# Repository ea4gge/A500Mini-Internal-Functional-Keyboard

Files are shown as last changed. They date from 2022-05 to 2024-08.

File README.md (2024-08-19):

# The A500Mini AmigaWave and RetroWiki's Internal Functional Keyboard Project

<br>
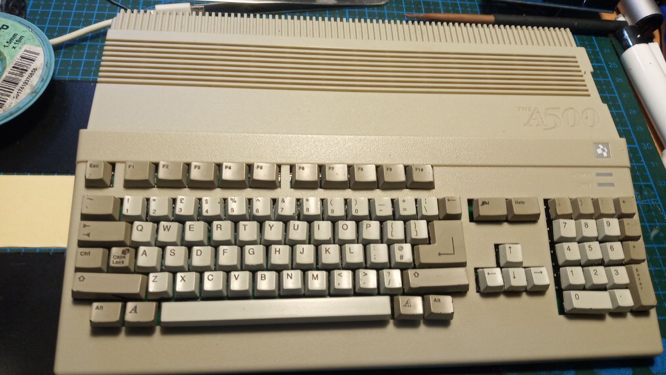
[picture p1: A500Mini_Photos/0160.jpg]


<br>

This is project of the A500Mini internal functional keyboard, based in 32U4 processor (Arduino leonardo, for example).

Actually it is working as final release, feel free to use, modify, recreate, ...

<br>
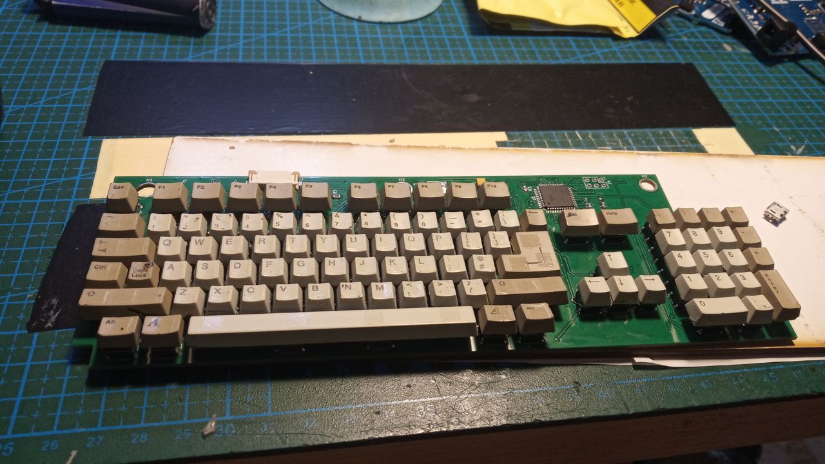
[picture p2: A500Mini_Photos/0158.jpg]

<br>

<br>
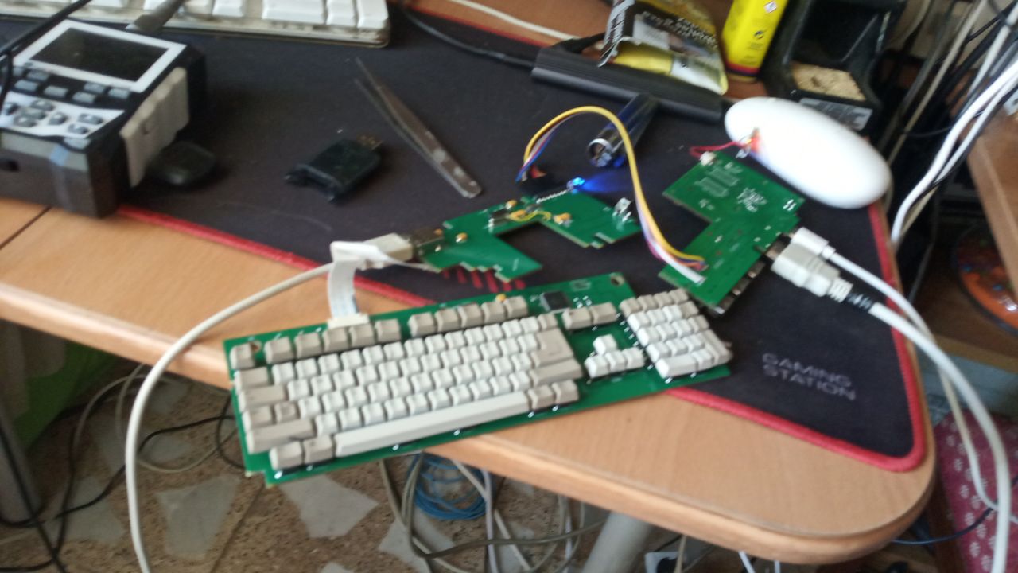
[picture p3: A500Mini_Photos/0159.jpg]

<br>

<br>
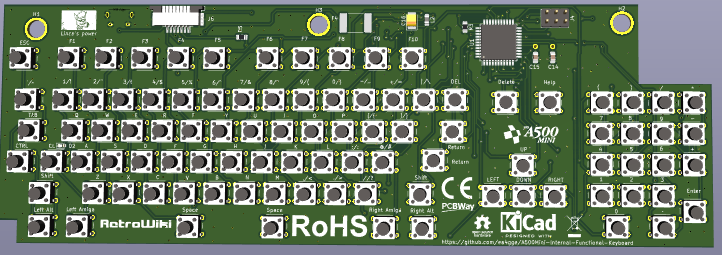
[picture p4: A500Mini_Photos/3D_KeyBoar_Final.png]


<br>

<br>
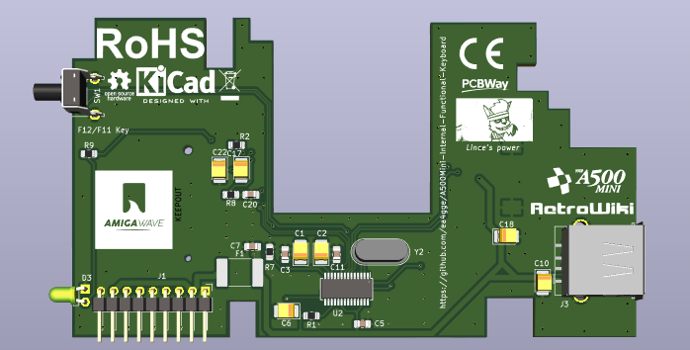
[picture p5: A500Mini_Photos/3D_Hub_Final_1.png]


<br>

# The features:

1.- HID internal fully functional keyboard, with F12 key in the "eject" button of the disk drive, CAPS Lock led, ...

2.- Internal 4 USB's HUB: One for the keyboard, one for the SD reader, one internal free (for network, for example) tha last one for the rear original placed USB on the main unit (because one of the original populated USB must be used por the hub's imput)

3.- SD card's reader exactly in the floppy disk's place.

4.- A lot of smiles after the fabrication :D 

The readme file and the help file for the fabrication is WIP at the moment.

All the mechanical procedures are made by Kikems_Retro.

The presentation of the first prototype  (one weekend JOB) was in the youtube's AmigaWave program. We have also presented in the "Posadas party", in Spain 

The inspiration for my own code was from the "Armapad36v2" because is my firstt program of an USB Keyboard. Many thanks for the Author of this!!!

Spetial thanks to EA4EOZ. He has had the idea of use the Eject button and gave me a lot of help in the code of the Arduino

<br>
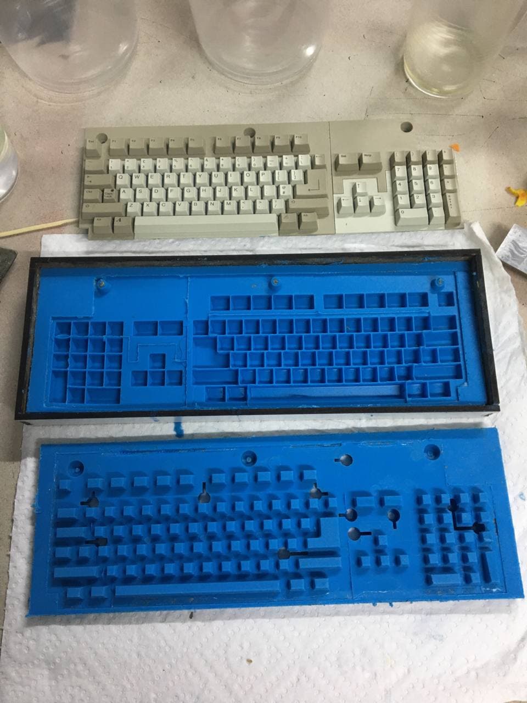
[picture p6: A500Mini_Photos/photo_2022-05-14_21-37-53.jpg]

<br>

<br>
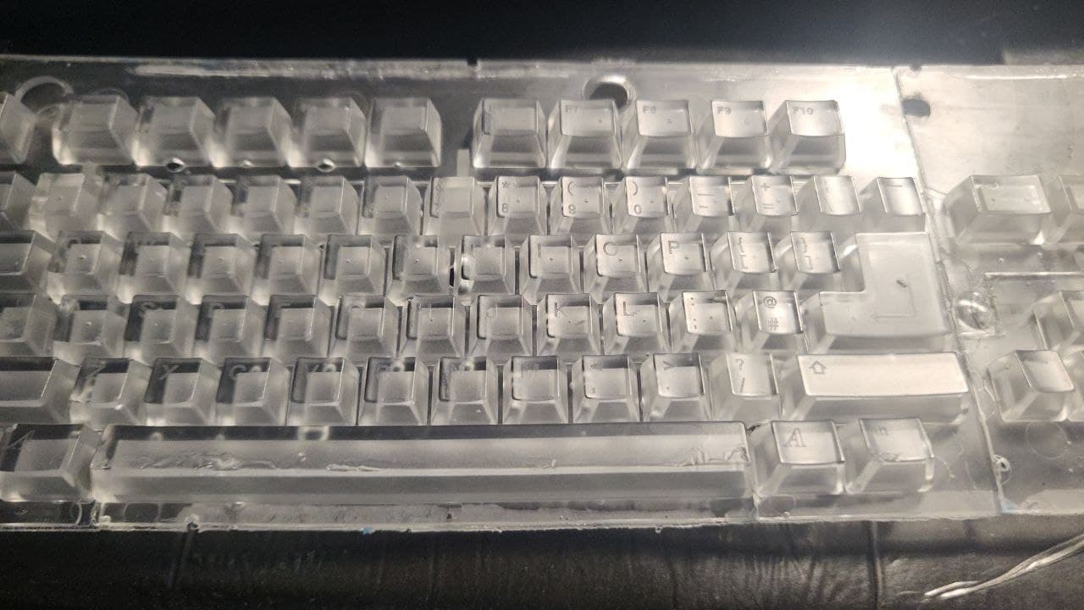
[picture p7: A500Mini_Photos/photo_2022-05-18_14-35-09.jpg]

<br>

Many thanks to all and Enjoy!!

Lince// EA4GGE

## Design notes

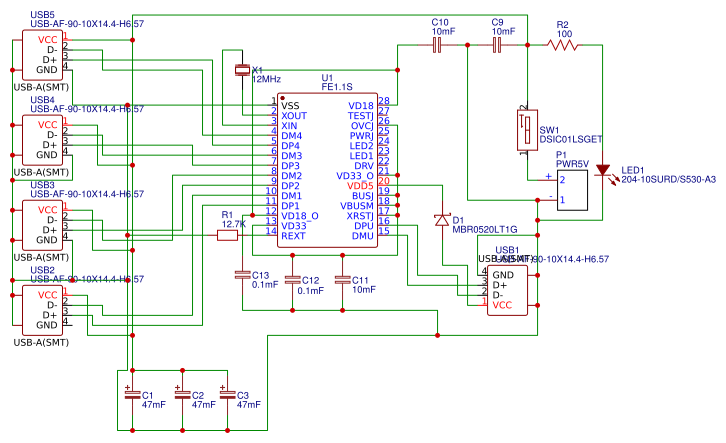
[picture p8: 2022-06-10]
FE11S_Schematic.png

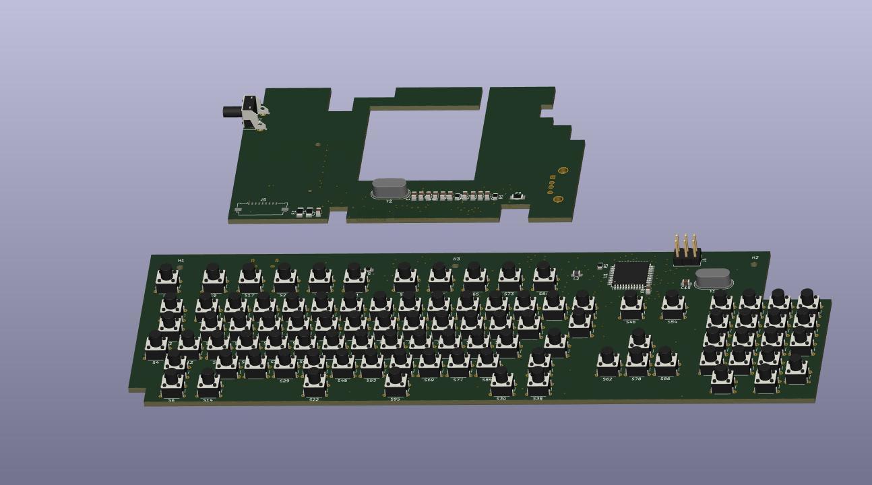
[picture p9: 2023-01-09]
3D_Model.jpg

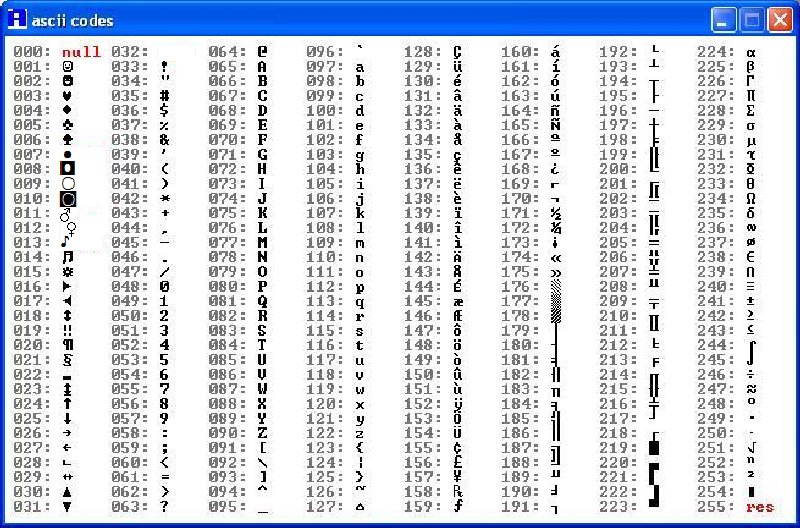
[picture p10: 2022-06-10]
ascii_code.jpg

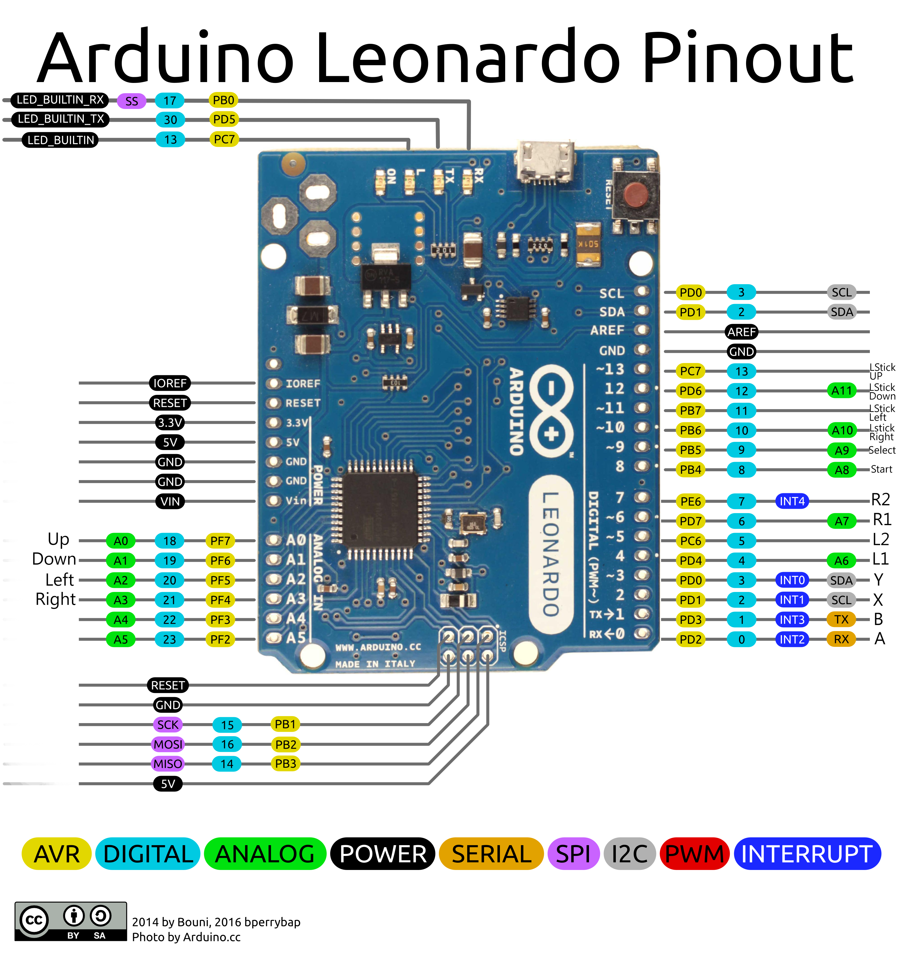
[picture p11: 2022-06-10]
41727827-dbd470d2-75a7-11e8-8bf4-4bd52fe4657b.png

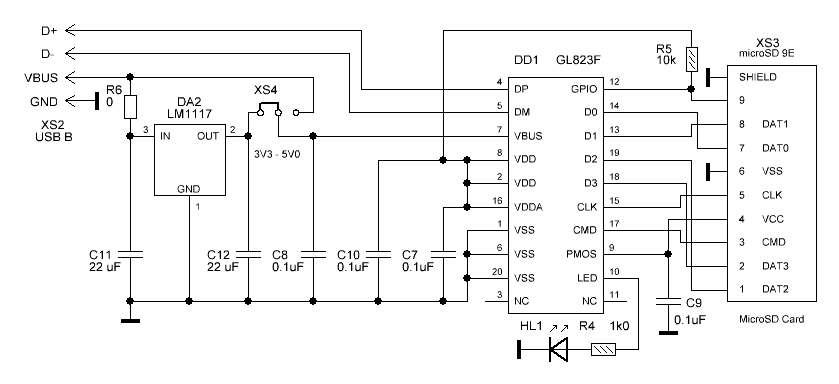
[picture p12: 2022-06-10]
anatomy-and-cloning-of-the-usb-adapter-for-sd-card-geektimes.gif

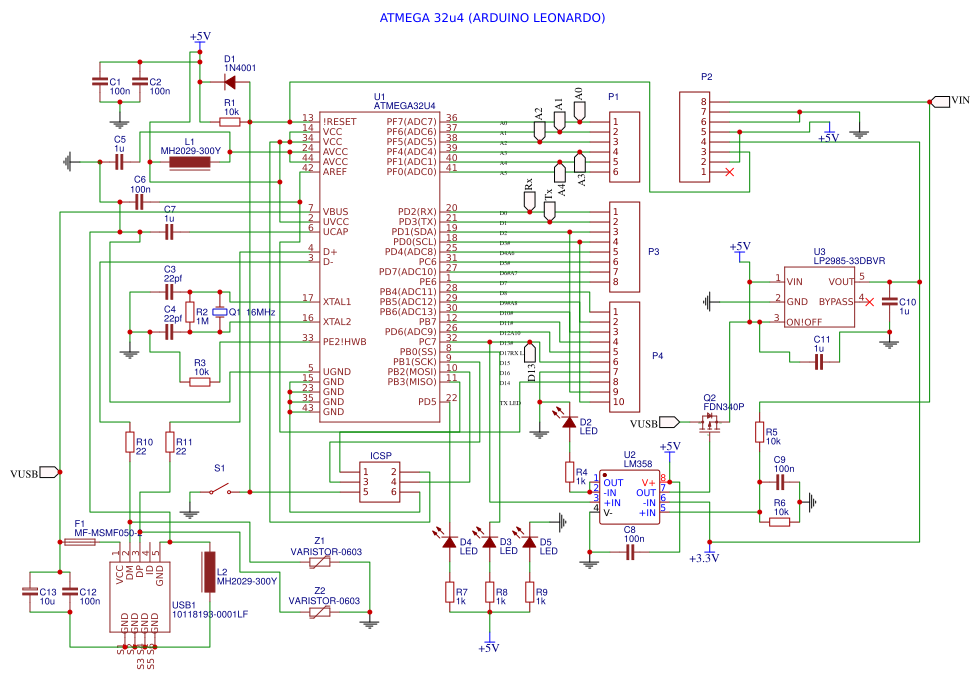
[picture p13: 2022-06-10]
Leonardo_compatible.png

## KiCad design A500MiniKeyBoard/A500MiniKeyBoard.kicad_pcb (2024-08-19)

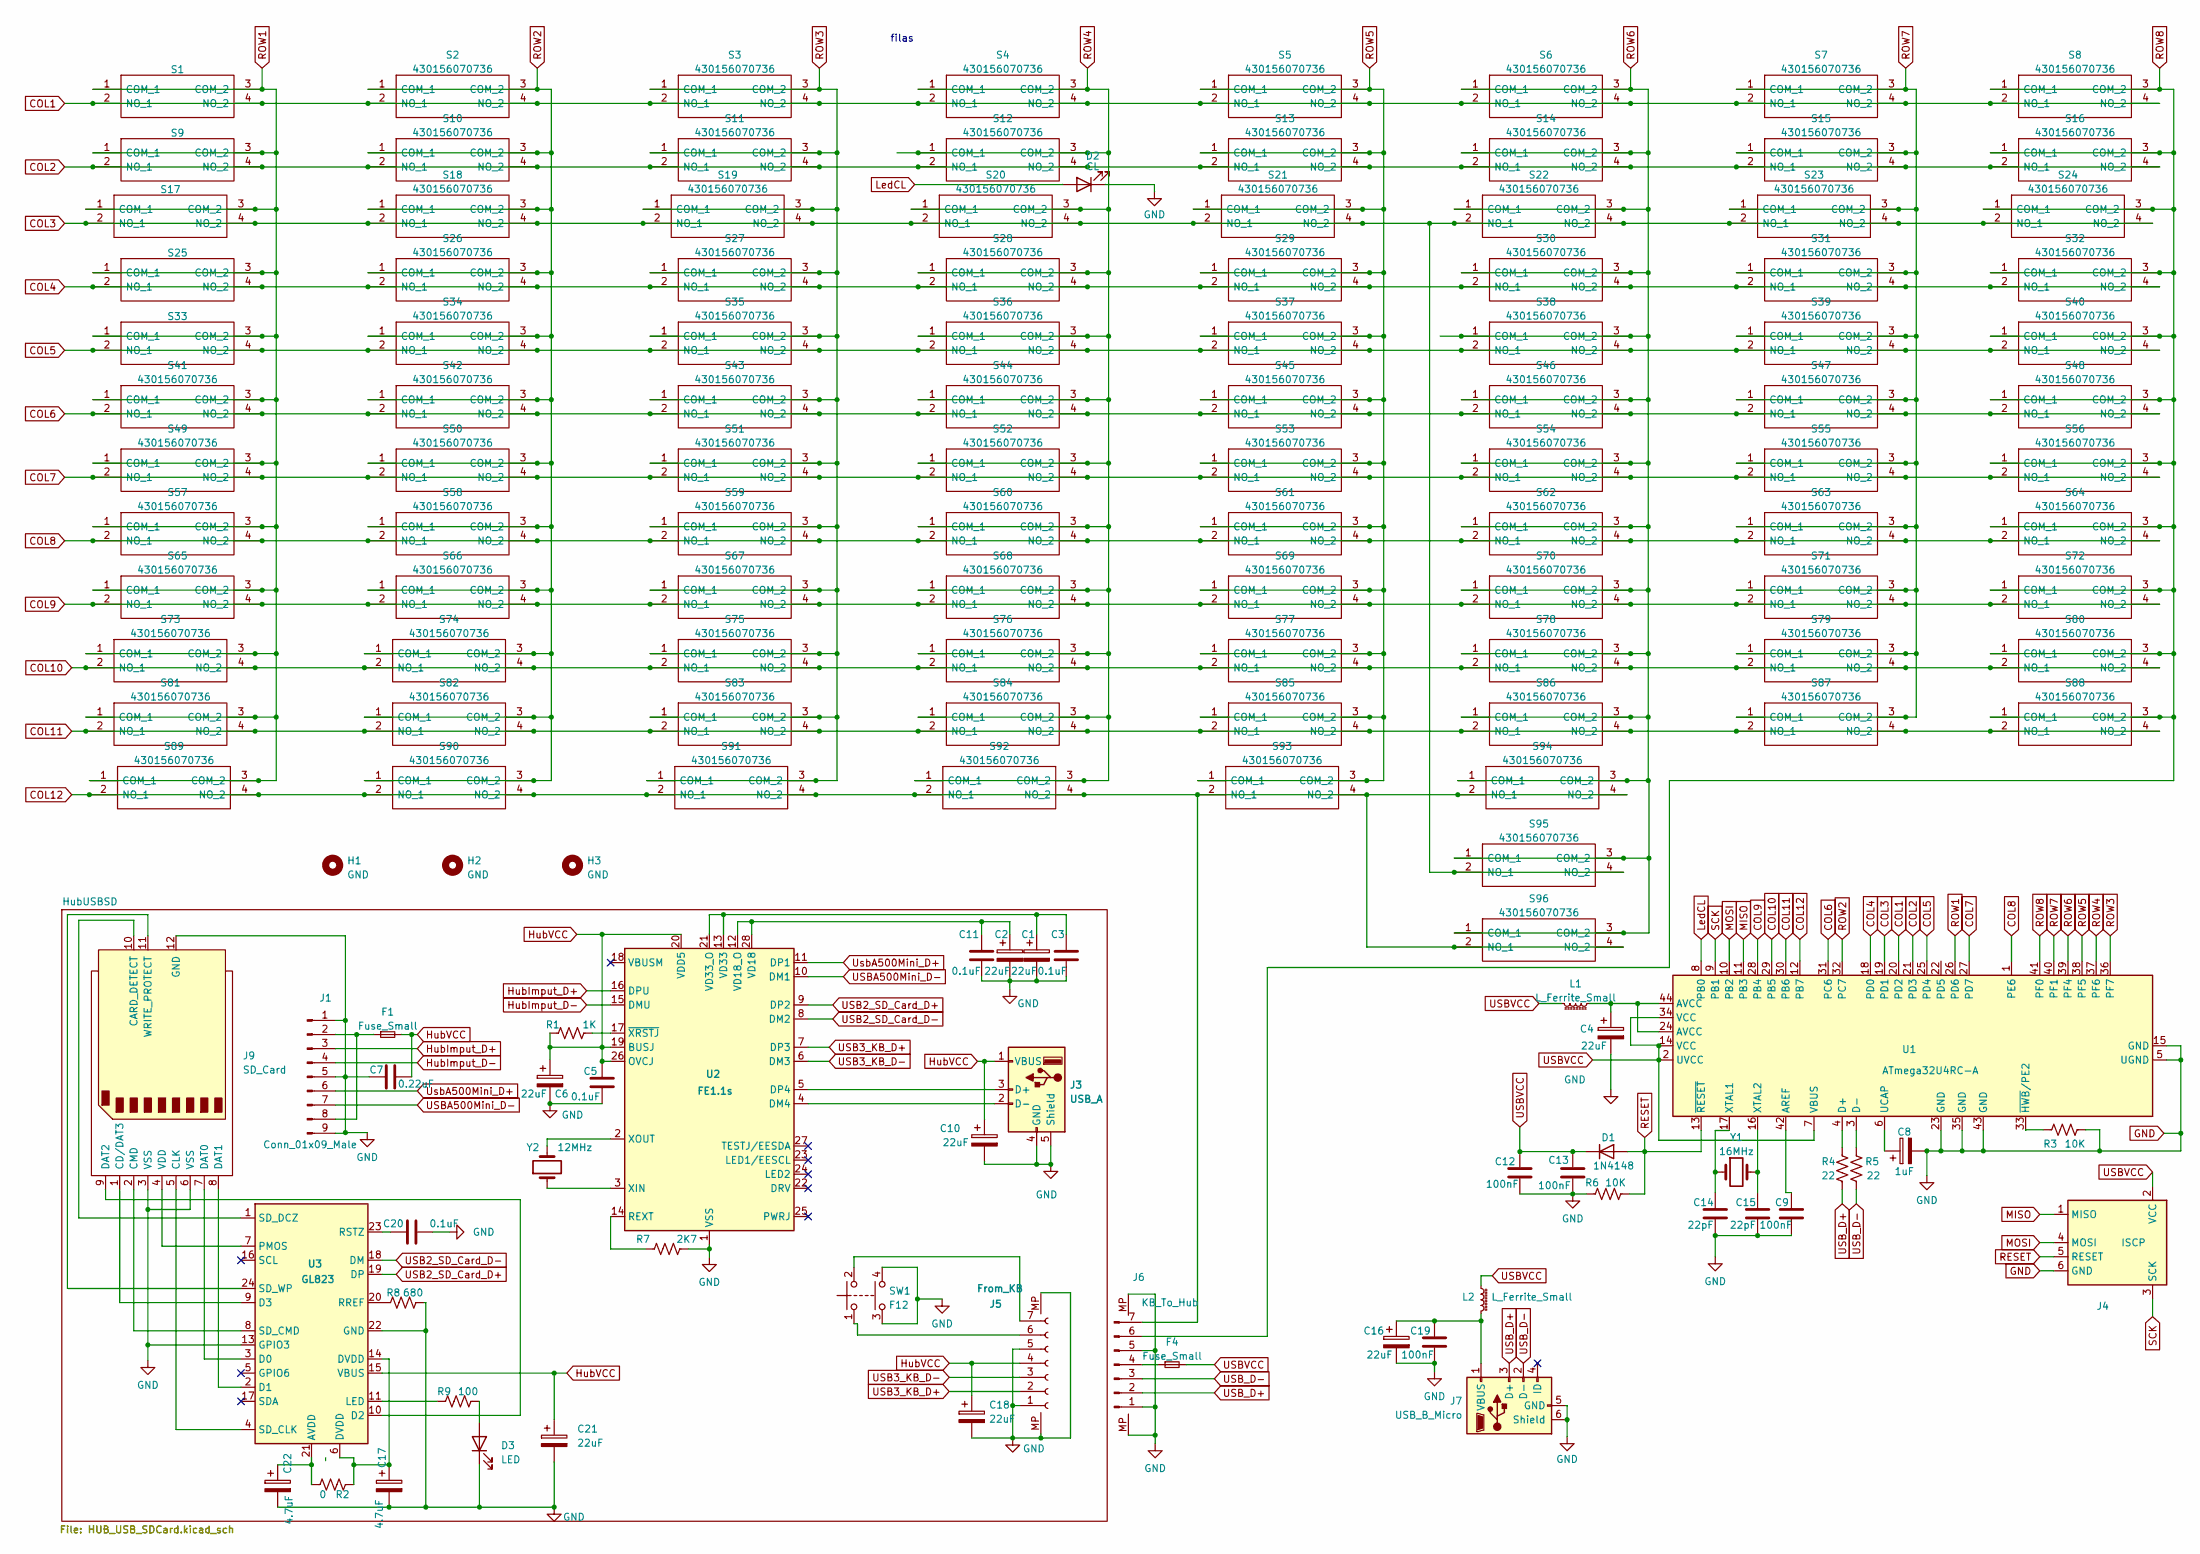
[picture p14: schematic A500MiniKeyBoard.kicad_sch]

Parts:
C1, C2, C4, C6, C10, C16, C18, C21: 22uF; CP_EIA-3528-21_Kemet-B_Pad1.50x2.35mm_HandSolder
C3, C5, C11, C20: 0.1uF; C_0805_2012Metric_Pad1.18x1.45mm_HandSolder
C7: 0.22uF; C_0805_2012Metric_Pad1.18x1.45mm_HandSolder
C8: 1uF; CP_EIA-3528-21_Kemet-B_Pad1.50x2.35mm_HandSolder
C9, C12, C13, C19: 100nF; C_0805_2012Metric_Pad1.18x1.45mm_HandSolder
C14, C15: 22pF; C_0805_2012Metric_Pad1.18x1.45mm_HandSolder
C17, C22: 4.7uF; CP_EIA-3528-21_Kemet-B_Pad1.50x2.35mm_HandSolder
D1: 1N4148; D_0805_2012Metric_Pad1.15x1.40mm_HandSolder
D2: CL; LED_0603_1608Metric
D3: LED; LED_D3.0mm_Horizontal_O1.27mm_Z2.0mm
F1, F4: Fuse_Small; Fuse_2920_7451Metric_Pad2.10x5.45mm_HandSolder
H1, H2, H3: GND; MountingHole_2.1mm
J1: Conn_01x09_Male; PinHeader_1x09_P2.54mm_Horizontal
J3: USB_A; USB_A_Molex_67643_Horizontal
J4: ISCP; PinHeader_2x03_P2.54mm_Vertical
J5: From_KB; TE_84953-7_1x07-1MP_P1.0mm_Horizontal
J6: KB_To_Hub; TE_84953-7_1x07-1MP_P1.0mm_Horizontal
J7: USB_B_Micro; USB_Micro-B_Amphenol_10118194_Horizontal
J9: SD_Card; SD_TE_2041021
L1, L2: L_Ferrite_Small; L_0805_2012Metric_Pad1.05x1.20mm_HandSolder
R1: 1K; R_0805_2012Metric_Pad1.20x1.40mm_HandSolder
R2: 0; R_0805_2012Metric_Pad1.20x1.40mm_HandSolder
R3, R6: 10K; R_0805_2012Metric_Pad1.20x1.40mm_HandSolder
R4, R5: 22; R_0805_2012Metric_Pad1.20x1.40mm_HandSolder
R7: 2K7; R_0805_2012Metric_Pad1.20x1.40mm_HandSolder
R8: 680; R_0805_2012Metric_Pad1.20x1.40mm_HandSolder
R9: 100; R_0805_2012Metric_Pad1.20x1.40mm_HandSolder
S1, S2, S3, S4, S5, S6, S7, S8, S9, S10, S11, S12, S13, S14, S15, S16, S17, S18, S19, S20, S21, S22, S23, S24, S25, S26, S27, S28, S29, S30, S31, S32, S33, S34, S35, S36, S37, S38, S39, S40, S41, S42, S43, S44, S45, S46, S47, S48, S49, S50, S51, S52, S53, S54, S55, S56, S57, S58, S59, S60, S61, S62, S63, S64, S65, S66, S67, S68, S69, S70, S71, S72, S73, S74, S75, S76, S77, S78, S79, S80, S81, S82, S83, S84, S85, S86, S87, S88, S89, S90, S91, S92, S93, S94, S95, S96: 430156070736; SW_PUSH_6mm_H7.3mm_mia; Mouser Part Number N/A
SW1: F12; SW_Tactile_SPST_Angled_PTS645Vx83-2LFS
U1: ATmega32U4RC-A; TQFP-44_10x10mm_P0.8mm
U2: FE1.1s; SSOP-28_3.9x9.9mm_P0.635mm
U3: GL823; SSOP-24_3.9x8.7mm_P0.635mm
Y1: 16MHz; Crystal_HC49-4H_Vertical
Y2: 12MHz; Crystal_HC49-4H_Vertical

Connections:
COL1: S1.2 (NO_1), S1.4 (NO_2), S2.2 (NO_1), S2.4 (NO_2), S3.2 (NO_1), S3.4 (NO_2), S4.2 (NO_1), S4.4 (NO_2), S5.2 (NO_1), S5.4 (NO_2), S6.2 (NO_1), S6.4 (NO_2), S7.2 (NO_1), S7.4 (NO_2), S8.2 (NO_1), S8.4 (NO_2), U1.20 (PD2)
COL2: S9.2 (NO_1), S9.4 (NO_2), S10.2 (NO_1), S10.4 (NO_2), S11.2 (NO_1), S11.4 (NO_2), S12.2 (NO_1), S12.4 (NO_2), S13.2 (NO_1), S13.4 (NO_2), S14.2 (NO_1), S14.4 (NO_2), S15.2 (NO_1), S15.4 (NO_2), S16.2 (NO_1), S16.4 (NO_2), U1.21 (PD3)
COL3: S17.2 (NO_1), S17.4 (NO_2), S18.2 (NO_1), S18.4 (NO_2), S19.2 (NO_1), S19.4 (NO_2), S20.2 (NO_1), S20.4 (NO_2), S21.2 (NO_1), S21.4 (NO_2), S22.2 (NO_1), S22.4 (NO_2), S23.2 (NO_1), S23.4 (NO_2), S24.2 (NO_1), S24.4 (NO_2), S95.2 (NO_1), S95.4 (NO_2), U1.19 (PD1)
COL4: S25.2 (NO_1), S25.4 (NO_2), S26.2 (NO_1), S26.4 (NO_2), S27.2 (NO_1), S27.4 (NO_2), S28.2 (NO_1), S28.4 (NO_2), S29.2 (NO_1), S29.4 (NO_2), S30.2 (NO_1), S30.4 (NO_2), S31.2 (NO_1), S31.4 (NO_2), S32.2 (NO_1), S32.4 (NO_2), U1.18 (PD0)
COL5: S33.2 (NO_1), S33.4 (NO_2), S34.2 (NO_1), S34.4 (NO_2), S35.2 (NO_1), S35.4 (NO_2), S36.2 (NO_1), S36.4 (NO_2), S37.2 (NO_1), S37.4 (NO_2), S38.2 (NO_1), S38.4 (NO_2), S39.2 (NO_1), S39.4 (NO_2), S40.2 (NO_1), S40.4 (NO_2), U1.25 (PD4)
COL6: S41.2 (NO_1), S41.4 (NO_2), S42.2 (NO_1), S42.4 (NO_2), S43.2 (NO_1), S43.4 (NO_2), S44.2 (NO_1), S44.4 (NO_2), S45.2 (NO_1), S45.4 (NO_2), S46.2 (NO_1), S46.4 (NO_2), S47.2 (NO_1), S47.4 (NO_2), S48.2 (NO_1), S48.4 (NO_2), U1.31 (PC6)
COL7: S49.2 (NO_1), S49.4 (NO_2), S50.2 (NO_1), S50.4 (NO_2), S51.2 (NO_1), S51.4 (NO_2), S52.2 (NO_1), S52.4 (NO_2), S53.2 (NO_1), S53.4 (NO_2), S54.2 (NO_1), S54.4 (NO_2), S55.2 (NO_1), S55.4 (NO_2), S56.2 (NO_1), S56.4 (NO_2), U1.27 (PD7)
COL8: S57.2 (NO_1), S57.4 (NO_2), S58.2 (NO_1), S58.4 (NO_2), S59.2 (NO_1), S59.4 (NO_2), S60.2 (NO_1), S60.4 (NO_2), S61.2 (NO_1), S61.4 (NO_2), S62.2 (NO_1), S62.4 (NO_2), S63.2 (NO_1), S63.4 (NO_2), S64.2 (NO_1), S64.4 (NO_2), U1.1 (PE6)
COL9: S65.2 (NO_1), S65.4 (NO_2), S66.2 (NO_1), S66.4 (NO_2), S67.2 (NO_1), S67.4 (NO_2), S68.2 (NO_1), S68.4 (NO_2), S69.2 (NO_1), S69.4 (NO_2), S70.2 (NO_1), S70.4 (NO_2), S71.2 (NO_1), S71.4 (NO_2), S72.2 (NO_1), S72.4 (NO_2), U1.28 (PB4)
COL10: S73.2 (NO_1), S73.4 (NO_2), S74.2 (NO_1), S74.4 (NO_2), S75.2 (NO_1), S75.4 (NO_2), S76.2 (NO_1), S76.4 (NO_2), S77.2 (NO_1), S77.4 (NO_2), S78.2 (NO_1), S78.4 (NO_2), S79.2 (NO_1), S79.4 (NO_2), S80.2 (NO_1), S80.4 (NO_2), U1.29 (PB5)
COL11: S81.2 (NO_1), S81.4 (NO_2), S82.2 (NO_1), S82.4 (NO_2), S83.2 (NO_1), S83.4 (NO_2), S84.2 (NO_1), S84.4 (NO_2), S85.2 (NO_1), S85.4 (NO_2), S86.2 (NO_1), S86.4 (NO_2), S87.2 (NO_1), S87.4 (NO_2), S88.2 (NO_1), S88.4 (NO_2), U1.30 (PB6)
COL12: J6.7, S89.2 (NO_1), S89.4 (NO_2), S90.2 (NO_1), S90.4 (NO_2), S91.2 (NO_1), S91.4 (NO_2), S92.2 (NO_1), S92.4 (NO_2), S93.2 (NO_1), S93.4 (NO_2), S94.2 (NO_1), S94.4 (NO_2), S96.2 (NO_1), S96.4 (NO_2), U1.12 (PB7)
GND: C1.2, C2.2, C3.1, C4.2, C5.1, C6.2, C7.1, C8.2, C9.2, C10.2, C11.2, C12.1, C13.1, C14.2, C15.2, C16.2, C17.2, C18.2, C19.1, C20.1, C21.2, C22.2, D2.1 (K), D3.1 (K), J1.1, J1.5, J1.9, J3.4 (GND), J3.5 (Shield), J4.6 (GND), J5.1, J5.5, J5.MP, J6.1, J6.5, J6.MP, J7.5 (GND), J7.6 (Shield), J9.3 (VSS), J9.6 (VSS), J9.12 (GND), R3.2, R6.1, R7.1, R8.1, SW1.3, SW1.4, U1.5 (UGND), U1.15 (GND), U1.23 (GND), U1.35 (GND), U1.43 (GND), U2.1 (VSS), U3.13 (GPIO3), U3.22 (GND)
HubImput_D+: J1.3, U2.16 (DPU)
HubImput_D-: J1.4, U2.15 (DMU)
HubVCC: C5.2, C6.1, C7.2, C10.1, C18.1, C21.1, F1.2, J3.1 (VBUS), J5.4, R1.2, U2.19 (BUSJ), U2.20 (VDD5), U2.26 (OVCJ), U3.15 (VBUS)
LedCL: D2.2 (A), U1.8 (PB0)
MISO: J4.1 (MISO), U1.11 (PB3)
MOSI: J4.4 (MOSI), U1.10 (PB2)
unnamed: C4.1, L1.1, U1.24 (AVCC), U1.44 (AVCC)
unnamed: C17.1, R2.2, U3.6 (DVDD), U3.14 (DVDD)
unnamed: D3.2 (A), R9.1
unnamed: F1.1, J1.2, J1.8
unnamed: J3.3 (D+), U2.5 (DP4)
unnamed: J3.2 (D-), U2.4 (DM4)
unnamed: J5.6, SW1.1
unnamed: J5.7, SW1.2
unnamed: F4.1, J6.4
unnamed: C16.1, C19.2, J7.1 (VBUS), L2.2
unnamed: J9.10 (CARD_DETECT), U3.1 (SD_DCZ)
unnamed: J9.1 (CD/DAT3), U3.9 (D3)
unnamed: J9.5 (CLK), U3.4 (SD_CLK)
unnamed: J9.2 (CMD), U3.8 (SD_CMD)
unnamed: J9.7 (DAT0), U3.3 (D0)
unnamed: J9.8 (DAT1), U3.2 (D1)
unnamed: J9.9 (DAT2), U3.10 (D2)
unnamed: J9.4 (VDD), U3.7 (PMOS)
unnamed: J9.11 (WRITE_PROTECT), U3.24 (SD_WP)
unnamed: C9.1, U1.42 (AREF)
unnamed: R4.1, U1.4 (D+)
unnamed: R5.1, U1.3 (D-)
unnamed: C8.1, U1.6 (UCAP)
unnamed: C14.1, U1.17 (XTAL1), Y1.1
unnamed: C15.1, U1.16 (XTAL2), Y1.2
unnamed: R3.1, U1.33 (~HWB/PE2)
unnamed: R7.2, U2.14 (REXT)
unnamed: C2.1, C11.1, U2.12 (VD18_O), U2.28 (VD18)
unnamed: C1.1, C3.2, U2.13 (VD33), U2.21 (VD33_O)
unnamed: U2.3 (XIN), Y2.1
unnamed: U2.2 (XOUT), Y2.2
unnamed: R1.1, U2.17 (~XRSTJ)
unnamed: C22.1, R2.1, U3.21 (AVDD)
unnamed: R9.2, U3.11 (LED)
unnamed: R8.2, U3.20 (RREF)
unnamed: C20.2, U3.23 (RSTZ)
RESET: D1.2 (A), J4.5 (RESET), R6.2, U1.13 (~RESET)
ROW1: S1.1 (COM_1), S1.3 (COM_2), S9.1 (COM_1), S9.3 (COM_2), S17.1 (COM_1), S17.3 (COM_2), S25.1 (COM_1), S25.3 (COM_2), S33.1 (COM_1), S33.3 (COM_2), S41.1 (COM_1), S41.3 (COM_2), S49.1 (COM_1), S49.3 (COM_2), S57.1 (COM_1), S57.3 (COM_2), S65.1 (COM_1), S65.3 (COM_2), S73.1 (COM_1), S73.3 (COM_2), S81.1 (COM_1), S81.3 (COM_2), S89.1 (COM_1), S89.3 (COM_2), U1.26 (PD6)
ROW2: S2.1 (COM_1), S2.3 (COM_2), S10.1 (COM_1), S10.3 (COM_2), S18.1 (COM_1), S18.3 (COM_2), S26.1 (COM_1), S26.3 (COM_2), S34.1 (COM_1), S34.3 (COM_2), S42.1 (COM_1), S42.3 (COM_2), S50.1 (COM_1), S50.3 (COM_2), S58.1 (COM_1), S58.3 (COM_2), S66.1 (COM_1), S66.3 (COM_2), S74.1 (COM_1), S74.3 (COM_2), S82.1 (COM_1), S82.3 (COM_2), S90.1 (COM_1), S90.3 (COM_2), U1.32 (PC7)
ROW3: S3.1 (COM_1), S3.3 (COM_2), S11.1 (COM_1), S11.3 (COM_2), S19.1 (COM_1), S19.3 (COM_2), S27.1 (COM_1), S27.3 (COM_2), S35.1 (COM_1), S35.3 (COM_2), S43.1 (COM_1), S43.3 (COM_2), S51.1 (COM_1), S51.3 (COM_2), S59.1 (COM_1), S59.3 (COM_2), S67.1 (COM_1), S67.3 (COM_2), S75.1 (COM_1), S75.3 (COM_2), S83.1 (COM_1), S83.3 (COM_2), S91.1 (COM_1), S91.3 (COM_2), U1.36 (PF7)
ROW4: S4.1 (COM_1), S4.3 (COM_2), S12.1 (COM_1), S12.3 (COM_2), S20.1 (COM_1), S20.3 (COM_2), S28.1 (COM_1), S28.3 (COM_2), S36.1 (COM_1), S36.3 (COM_2), S44.1 (COM_1), S44.3 (COM_2), S52.1 (COM_1), S52.3 (COM_2), S60.1 (COM_1), S60.3 (COM_2), S68.1 (COM_1), S68.3 (COM_2), S76.1 (COM_1), S76.3 (COM_2), S84.1 (COM_1), S84.3 (COM_2), S92.1 (COM_1), S92.3 (COM_2), U1.37 (PF6)
ROW5: S5.1 (COM_1), S5.3 (COM_2), S13.1 (COM_1), S13.3 (COM_2), S21.1 (COM_1), S21.3 (COM_2), S29.1 (COM_1), S29.3 (COM_2), S37.1 (COM_1), S37.3 (COM_2), S45.1 (COM_1), S45.3 (COM_2), S53.1 (COM_1), S53.3 (COM_2), S61.1 (COM_1), S61.3 (COM_2), S69.1 (COM_1), S69.3 (COM_2), S77.1 (COM_1), S77.3 (COM_2), S85.1 (COM_1), S85.3 (COM_2), S93.1 (COM_1), S93.3 (COM_2), U1.38 (PF5)
ROW6: S6.1 (COM_1), S6.3 (COM_2), S14.1 (COM_1), S14.3 (COM_2), S22.1 (COM_1), S22.3 (COM_2), S30.1 (COM_1), S30.3 (COM_2), S38.1 (COM_1), S38.3 (COM_2), S46.1 (COM_1), S46.3 (COM_2), S54.1 (COM_1), S54.3 (COM_2), S62.1 (COM_1), S62.3 (COM_2), S70.1 (COM_1), S70.3 (COM_2), S78.1 (COM_1), S78.3 (COM_2), S86.1 (COM_1), S86.3 (COM_2), S94.1 (COM_1), S94.3 (COM_2), S95.1 (COM_1), S95.3 (COM_2), S96.1 (COM_1), S96.3 (COM_2), U1.39 (PF4)
ROW7: S7.1 (COM_1), S7.3 (COM_2), S15.1 (COM_1), S15.3 (COM_2), S23.1 (COM_1), S23.3 (COM_2), S31.1 (COM_1), S31.3 (COM_2), S39.1 (COM_1), S39.3 (COM_2), S47.1 (COM_1), S47.3 (COM_2), S55.1 (COM_1), S55.3 (COM_2), S63.1 (COM_1), S63.3 (COM_2), S71.1 (COM_1), S71.3 (COM_2), S79.1 (COM_1), S79.3 (COM_2), S87.1 (COM_1), S87.3 (COM_2), U1.40 (PF1)
ROW8: J6.6, S8.1 (COM_1), S8.3 (COM_2), S16.1 (COM_1), S16.3 (COM_2), S24.1 (COM_1), S24.3 (COM_2), S32.1 (COM_1), S32.3 (COM_2), S40.1 (COM_1), S40.3 (COM_2), S48.1 (COM_1), S48.3 (COM_2), S56.1 (COM_1), S56.3 (COM_2), S64.1 (COM_1), S64.3 (COM_2), S72.1 (COM_1), S72.3 (COM_2), S80.1 (COM_1), S80.3 (COM_2), S88.1 (COM_1), S88.3 (COM_2), U1.41 (PF0)
SCK: J4.3 (SCK), U1.9 (PB1)
USB2_SD_Card_D+: U2.9 (DP2), U3.19 (DP)
USB2_SD_Card_D-: U2.8 (DM2), U3.18 (DM)
USB3_KB_D+: J5.2, U2.7 (DP3)
USB3_KB_D-: J5.3, U2.6 (DM3)
USBA500Mini_D-: J1.7, U2.10 (DM1)
USBVCC: C12.2, C13.2, D1.1 (K), F4.2, J4.2 (VCC), L1.2, L2.1, U1.2 (UVCC), U1.7 (VBUS), U1.14 (VCC), U1.34 (VCC)
USB_D+: J6.2, J7.3 (D+), R4.2
USB_D-: J6.3, J7.2 (D-), R5.2
UsbA500Mini_D+: J1.6, U2.11 (DP1)

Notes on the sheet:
filas

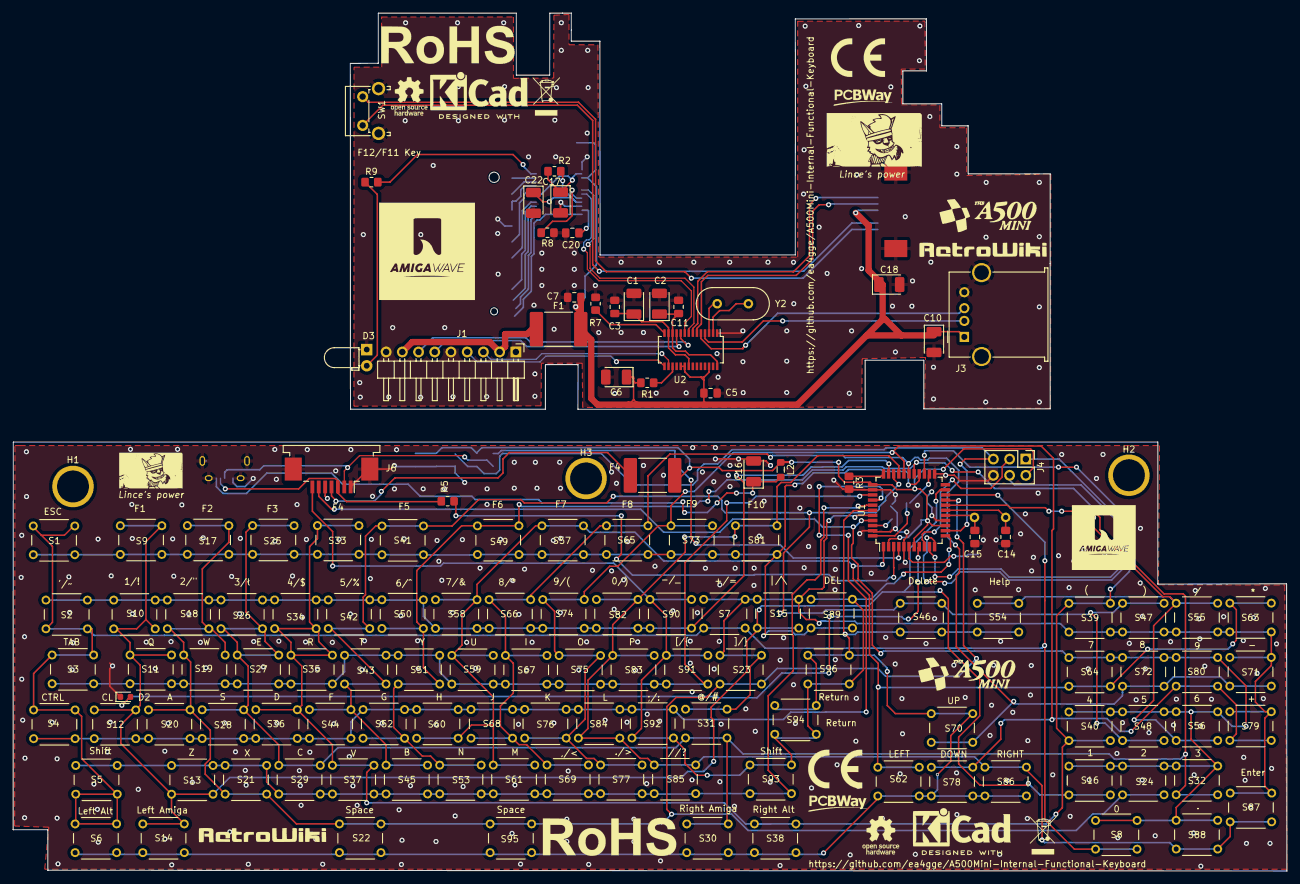
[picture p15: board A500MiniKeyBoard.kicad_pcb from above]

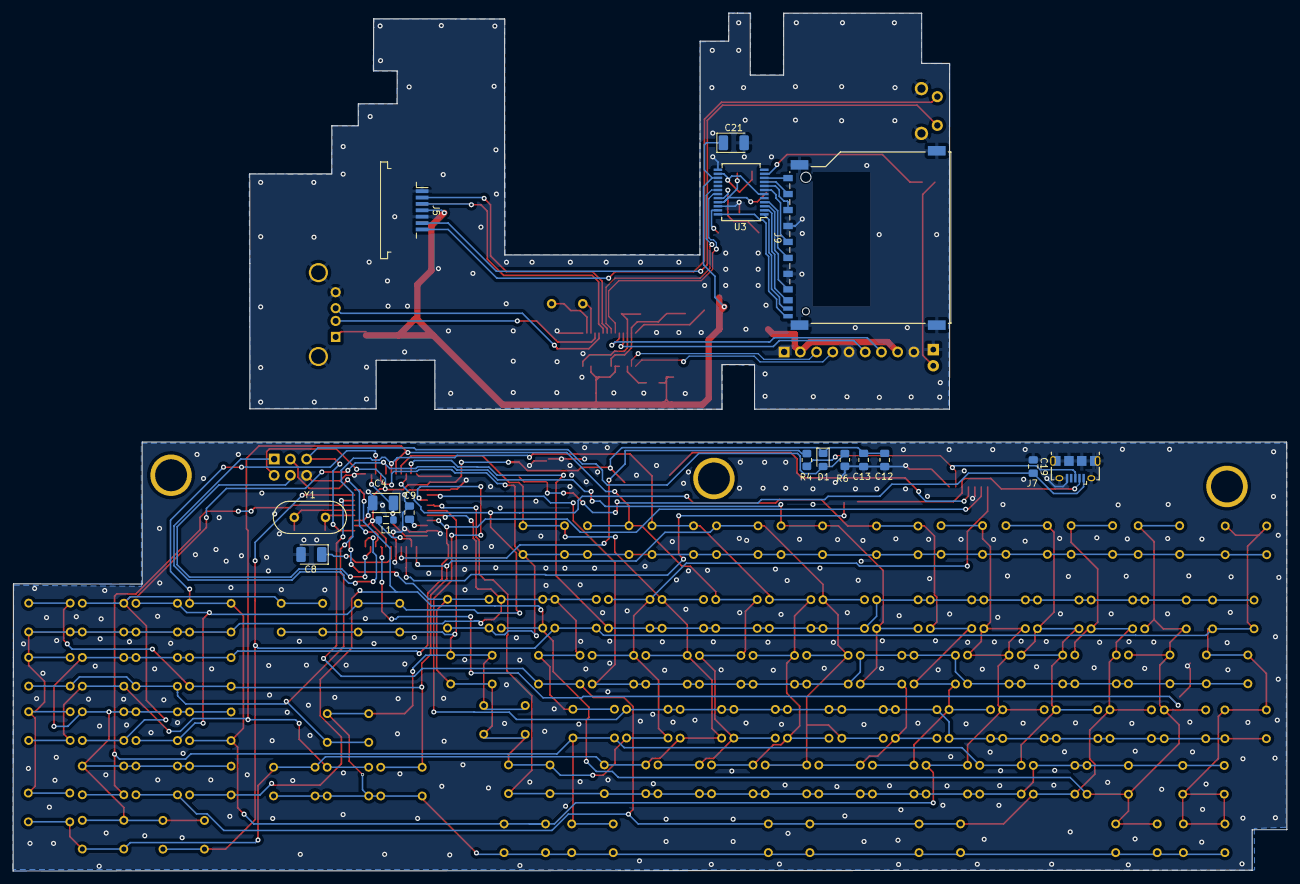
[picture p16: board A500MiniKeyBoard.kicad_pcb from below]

Board: 2 copper layers, 199.5 x 67.2 mm, 166 parts (16 on the bottom side), 74 nets.

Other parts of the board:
G6, G13: LOGO; pcbway_10X3_3
G7: LOGO; Logo_Lince_15X8
G8, G10: LOGO; theA500Mini_16_9X16_9
G9: LOGO; Logo_Lince_10X6
REF1, REF11: RoHS-Logo_6mm_SilkScreen
REF2, REF15: KiCad-Logo2_6mm_SilkScreen
REF3, REF14: OSHW-Logo_5.7x6mm_SilkScreen
REF4, REF16: WEEE-Logo_4.2x6mm_SilkScreen
REF5, REF12: CE-Logo_8.5x6mm_SilkScreen

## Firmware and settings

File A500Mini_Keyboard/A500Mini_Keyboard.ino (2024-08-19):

//####################################################################################################
//## Keyboard software for the A500Mini. It is created for an Arduino Leonardo, using it pinout.    ##
//## The final implementation is for 32U4 micro directly, to the RetroWiki's keyboard design.       ##
//## The project was created between Kikems_retro and Lince (ea4gge).                               ##
//## This soft was inspired on the soft of the project "Armapad36v2". I has it as example for       ##
//## this project. Actually here are nothing about that but it was my oun inspiration for the start ##
//## Many thanks to the creator of the software, it was esential for my own one.                    ##
//## Keypad by Community https://github.com/Chris--A/Keypad version 3.1.1                           ##
//## HID-Project by NicoHood https://github.com/NicoHood/HID version 2.8.2                          ##
//## Spetial TNANKS to Miguel Angel Vallejo, EA4EOZ. He gave us a great help during the Project     ##
//## You are free to use this code under GNU General Public License. You can use, distribute and    ##
//## modify  ONLY sharing all the changes for free. Read the License's Document for details.        ##
//####################################################################################################


//Keypad by Community https://github.com/Chris--A/Keypad version 3.1.1
#include <Keypad.h>

// HID-Project by NicoHood https://github.com/NicoHood/HID version 2.8.2
#include "HID-Project.h"

const byte capsLed = LED_BUILTIN_RX;
const byte ROWS = 8;
const byte COLS = 12;
byte colPins[COLS] = { 0,  1,  2,  3,  4,  5,  6,  7,  8,  9,  10,  11};
byte rowPins[ROWS] = {12, 13, 18, 19, 20, 21, 22, 23};

// American Amiga layout
byte directKeys[ROWS][COLS] = {
//    0 (COL 1)       1 (COL 2)      2 (COL 3)        3 (COL 4)       4 (COL 5)      5 (COL 6)         6 (COL 7)      7 (COL 8)       8 (COL 9)       9 (COL 10)      10 (COL 11)       11  (COL 12)
// ==============  =============  ===============  ==============  ==============  ===============  =============  ===============  ===============  ==============  ===============  ===============  
  {KEY_ESC,        KEY_F1,        KEY_F2,          KEY_F3,         KEY_F4,         KEY_F5,          KEY_F6,        KEY_F7,          KEY_F8,          KEY_F9,         KEY_F10,         KEY_BACKSPACE   }, // 12     (ROW 1)
  {KEY_QUOTE,      KEY_1,         KEY_2,           KEY_3,          KEY_4,          KEY_5,           KEY_6,         KEY_7,           KEY_8,           KEY_9,          KEY_0,           KEY_MINUS       }, // 13     (ROW 2)
  {KEY_TAB,        KEY_Q,         KEY_W,           KEY_E,          KEY_R,          KEY_T,           KEY_Y,         KEY_U,           KEY_I,           KEY_O,          KEY_P,           KEY_LEFT_BRACE  }, // A0 (18)(ROW 3)
  {KEY_LEFT_CTRL,  KEY_CAPS_LOCK, KEY_A,           KEY_S,          KEY_D,          KEY_F,           KEY_G,         KEY_H,           KEY_J,           KEY_K,          KEY_L,           KEY_SEMICOLON   }, // A1 (19)(ROW 4)
  {KEY_LEFT_SHIFT, KEY_Z,         KEY_X,           KEY_C,          KEY_V,          KEY_B,           KEY_N,         KEY_M,           KEY_COMMA,       KEY_PERIOD,     KEY_SLASH,       KEY_RIGHT_SHIFT }, // A2 (20)(ROW 5)
  {KEY_LEFT_ALT,   KEY_LEFT_GUI,  KEY_SPACE,       KEY_RIGHT_GUI,  KEY_RIGHT_ALT,  KEY_DELETE,      KEY_PAGE_DOWN, KEY_LEFT_ARROW,  KEY_UP_ARROW,    KEY_DOWN_ARROW, KEY_RIGHT_ARROW, KEY_RETURN      }, // A3 (21)(ROW 6)
  {KEY_EQUAL,      KEY_BACKSLASH, KEY_RIGHT_BRACE, KEY_QUOTE,      KEY_LEFT_BRACE, KEY_RIGHT_BRACE, KEYPAD_DIVIDE, KEYPAD_MULTIPLY, KEYPAD_SUBTRACT, KEYPAD_ADD,     KEYPAD_ENTER,    KEY_F11         }, // A4 (22)(ROW 7)
  {KEYPAD_0,       KEYPAD_1,      KEYPAD_2,        KEYPAD_3,       KEYPAD_4,       KEYPAD_5,        KEYPAD_6,      KEYPAD_7,        KEYPAD_8,        KEYPAD_9,       KEYPAD_DOT,      KEY_F12         }  // A5 (23)(ROW 8)
};

Keypad kpd = Keypad(makeKeymap(directKeys), rowPins, colPins, ROWS, COLS);



void setup() {
  pinMode(capsLed, OUTPUT);

  // Sends a clean report to the host. This is important on any Arduino type.
  BootKeyboard.begin();
}


void loop() {
  //
  // Update CapsLock Led
  //
  if (BootKeyboard.getLeds() & LED_CAPS_LOCK)
    digitalWrite(capsLed, HIGH);
  else
    digitalWrite(capsLed, LOW);



  //
  // Process keys
  //
  if (kpd.getKeys()) {
    for (int i=0; i<LIST_MAX; i++){  // Scan the whole key list.
      if (kpd.key[i].stateChanged){  // Only find keys that have changed state.
        switch (kpd.key[i].kstate){  // Report changes to host

          case PRESSED:
            BootKeyboard.press(KeyboardKeycode(kpd.key[i].kchar));
            break;

          case HOLD:
            break;
                    
          case RELEASED:
            BootKeyboard.release(KeyboardKeycode(kpd.key[i].kchar));
            break;
                    
          case IDLE:
            break;
        }
      }
    }
  }
}

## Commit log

2022-05-17 Add files via upload
    Arduino code for A500MiniKeyb
2022-05-23 Add files via upload
    Keyboard with the Issues "multiple keys" and "keyPad" solved. Old is in the .Bak file
    [A500Mini_Keyboard.ino]
